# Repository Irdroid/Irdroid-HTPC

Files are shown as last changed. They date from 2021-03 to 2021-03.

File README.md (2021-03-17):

**Irdroid HTPC Infrared Remote Control Receiver for Kodi and alternatives**
-
**Introduction** 

The Irdroid-HTPC is a USB Infrared Remote Control receiver for HTPC media centers such as  KODI, Plex, Emby, OSMC, Jellyfin, Stremio etc. It enumerates on the host system as a standard HID input device (keyboard) and sends keystrokes to the host system based on the pressed TV remote control key. .(https://irdroid.eu/product/irdroid-htpc-infrared-remote-control-receiver-kodi-alternatives/)

**Product Photo:**
-

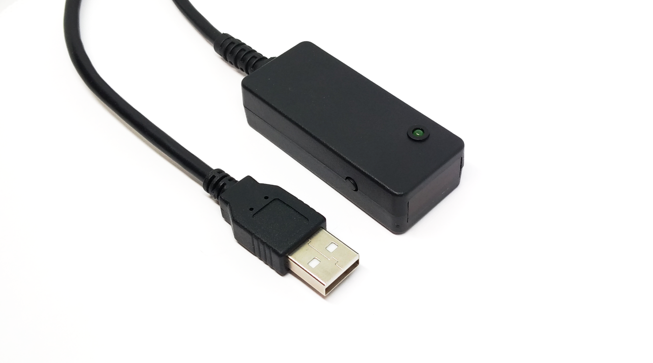
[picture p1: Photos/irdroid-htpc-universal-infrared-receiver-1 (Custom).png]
Irdroid-HTPC


**Features:**
-
- Usb Infrared remote control receiver for your HTPC that supports Kodi, Plex, Emby etc.
- Control your HTPC with your TV remote or any other remote
- No drivers needed, enumerates as a usb keyboard
- Infrared receiver with ultra wide reception angle with great sensitivity
- Kodi addon for activating shortcuts for Favourites and Weather via a single button.
- Velcro dots for fixing the unit in a position

**Supported Operating Systems**
-
- GNU Linux
- Mac OS X
- MS Windows
- Android

In addition to the above the module is open source hardware and software , so if you need to do any changes or fork your own version you are free to do so!
Its shipped with the micronucleus bootloader, compatible with the Arduino IDE and in a manner of minutes you can do whatever changes you need by simply plugging the usb cable of the device to your pc and changing the code as per your needs.
Irdroid-HTPC Remote Receiver has a great range and you don’t have to point your remote control directly toward the device it in order to control your media center.

**You have the following keystrokes available for remotely controlling your media center:**
- UP
- DOWN
- LEFT
- RIGHT
- OK/Enter
- Back
- Navigate to Favourites
- Navigate to Weather
- Play/Pause
 
With the above you get full control of your HTPC media center and if you need additional keystrokes / more control you can reprogram it by using the Arduino IDE.

**Product website and Documentation**
-
- [Irdroid-HTPC product Website](https://irdroid.eu/product/irdroid-htpc-infrared-remote-control-receiver-kodi-alternatives/)
- [Documentation, Schematics, Production files and Software for Brickz can be found in this repository.](https://github.com/Irdroid/Irdroid-HTPC)

**Purchase sample unit**
-
- [Irdroid-HTPC product Website](https://irdroid.eu/product/irdroid-htpc-infrared-remote-control-receiver-kodi-alternatives/)

**You want to help with the development?**
-
- Write us an email to info@irdroid.com

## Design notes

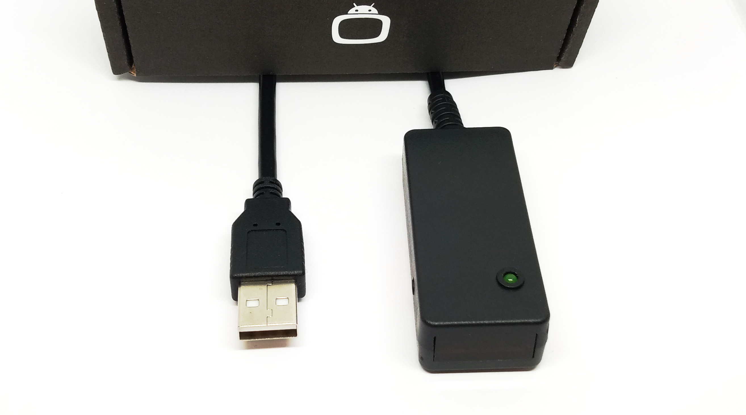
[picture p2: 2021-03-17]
Photos/irdroid-htpc-universal-infrared-receiver-2.png

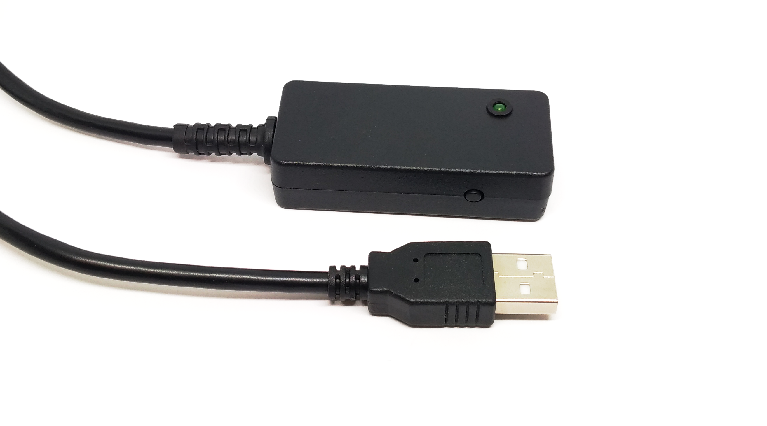
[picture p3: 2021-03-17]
Photos/irdroid-htpc-universal-infrared-receiver-3.png

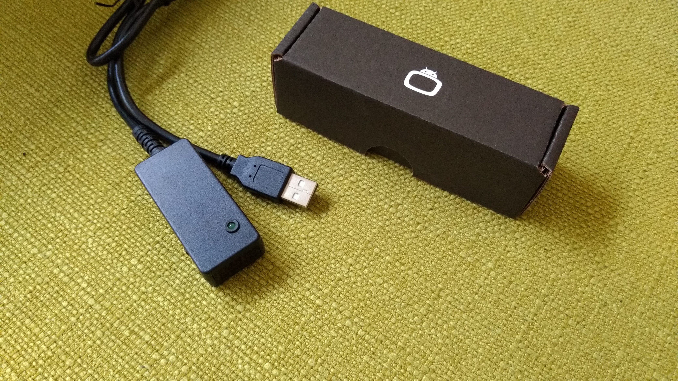
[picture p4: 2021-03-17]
Photos/irdroid-htpc-universal-infrared-receiver-blog2.jpg

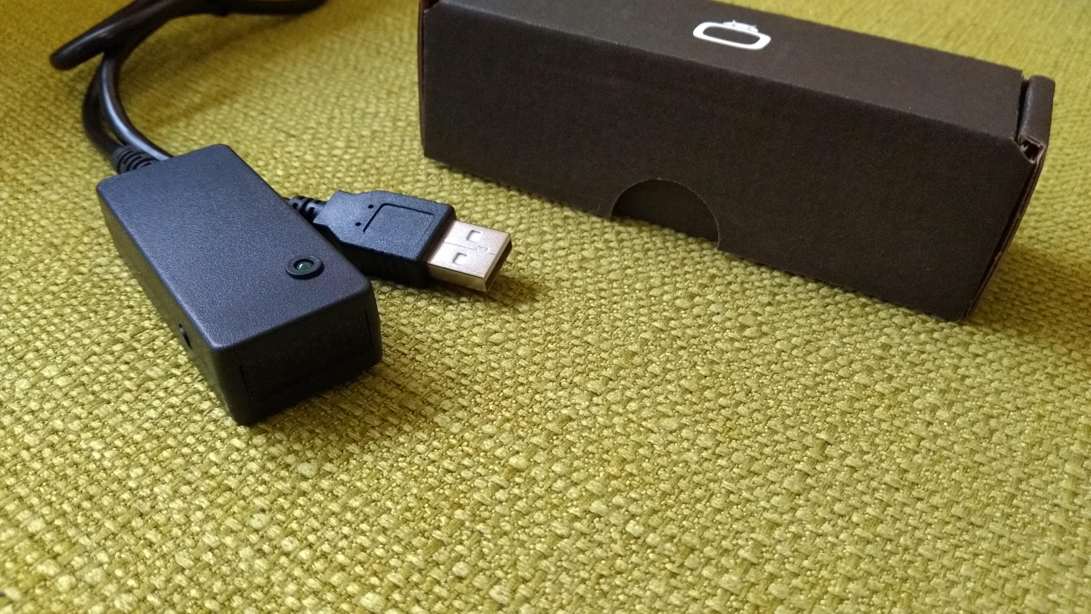
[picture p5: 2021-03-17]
Photos/irdroid-htpc-universal-infrared-receiver-blog1.jpg

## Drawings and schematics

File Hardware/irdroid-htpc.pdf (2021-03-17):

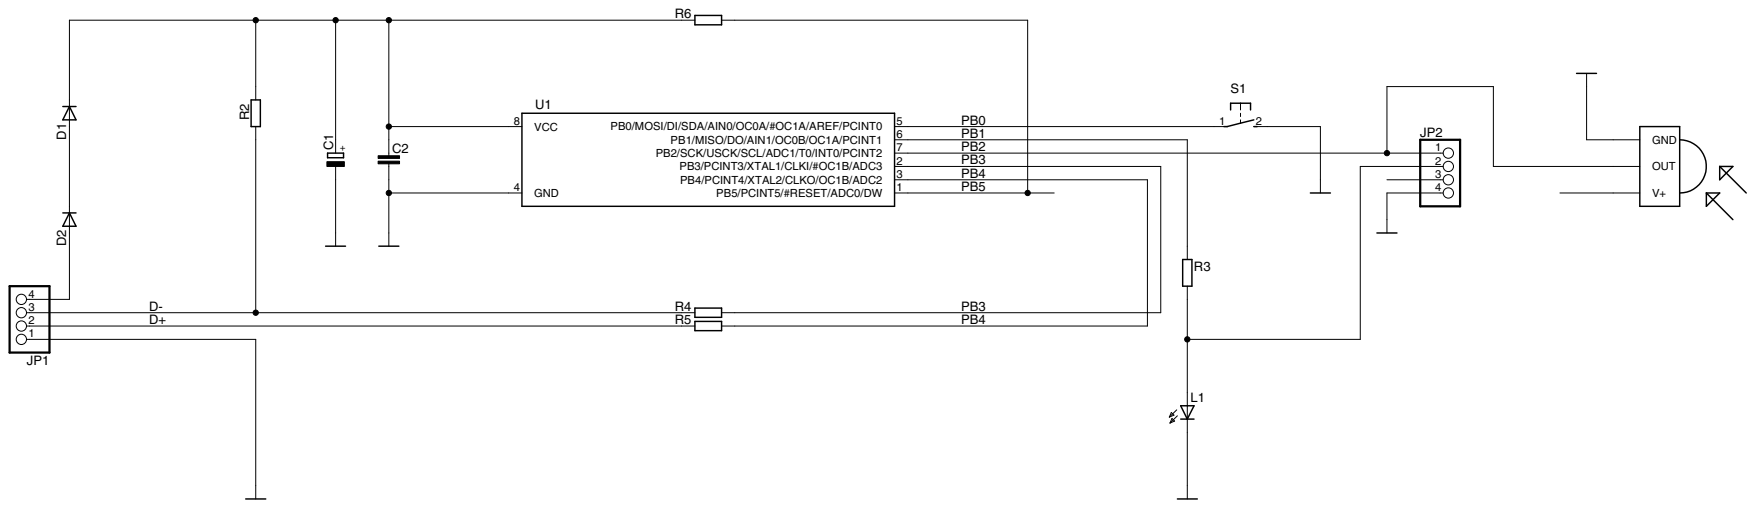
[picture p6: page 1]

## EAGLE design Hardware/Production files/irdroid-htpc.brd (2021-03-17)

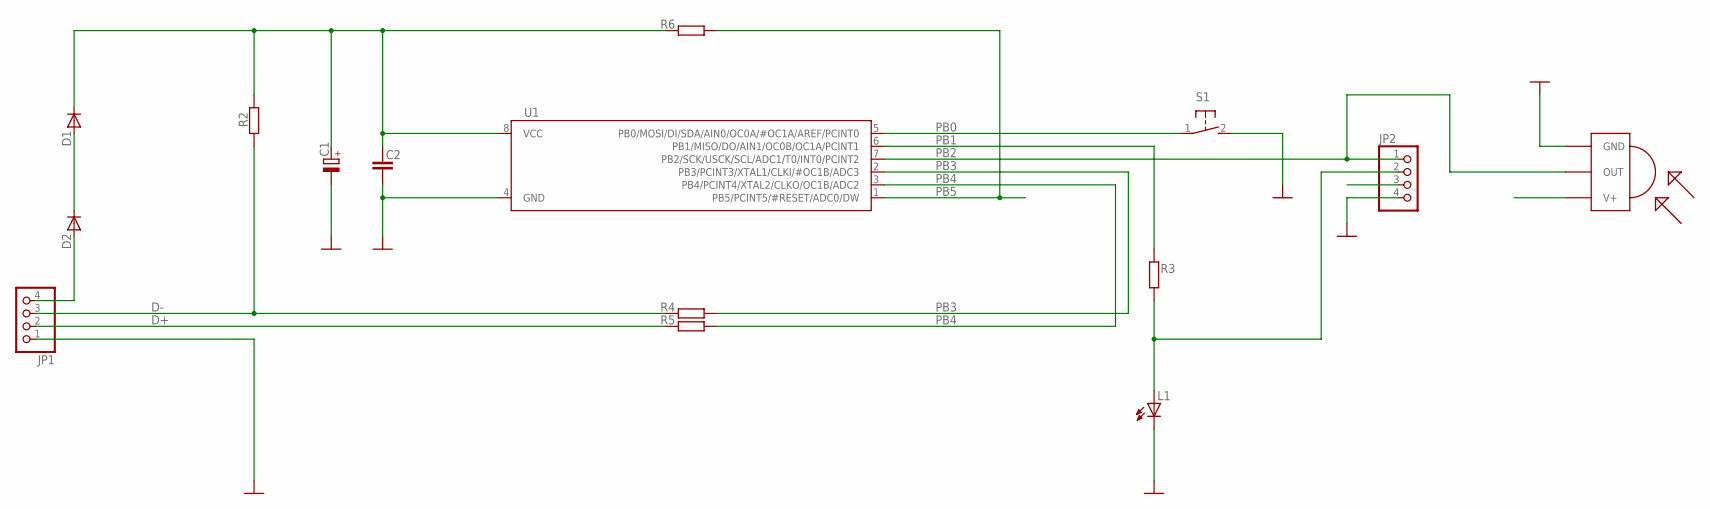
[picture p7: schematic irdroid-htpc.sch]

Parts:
C1: CPOL-EUE2-5; E2-5
C2: C-EU025-025X050; C025-025X050
D1, D2: DDO35; DO35-200MILS
JP1, JP2: PINHD-1X4; 1X04
L1: LED3.0MM; LED-3.0MM
R2, R3, R4, R5, R6: R-EU_0204/5; 0204/5
S1: 31-XX; B3F-31XX
U1: ATTINY85-20PU; DIP8
U$1: TSOP1838; TSOP18XX

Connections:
D+: JP1.2, R5.1
D-: JP1.3, R2.1, R4.1
GND: C1.-, C2.2, JP1.1, JP2.4, L1.K (C), S1.2 (S), U1.4 (GND), U$1.GND
unnamed: D1.A, D2.K
unnamed: JP2.2, L1.A, R3.1
PB0: S1.1, U1.5 (PB0/MOSI/DI/SDA/AIN0/OC0A/#OC1A/AREF/PC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)
PB1: R3.2, U1.6 (PB1/MISO/DO/AIN1/OC0B/OC1A/PCINT1)
PB2: JP2.1, U1.7 (PB2/SCK/USCK/SCL/ADC1/T0/INT0/PCINT2), U$1.OUT
PB3: R4.2, U1.2 (PB3/PCINT3/XTAL1/CLKI/#OC1B/ADC3)
PB4: R5.2, U1.3 (PB4/PCINT4/XTAL2/CLKO/OC1B/ADC2)
PB5: R6.2, U1.1 (PB5/PCINT5/#RESET/ADC0/DW)
VBUS: D2.A, JP1.4
VCC: C1.+, C2.1, D1.K, JP2.3, R2.2, R6.1, U1.8 (VCC), U$1.VCC (V+)

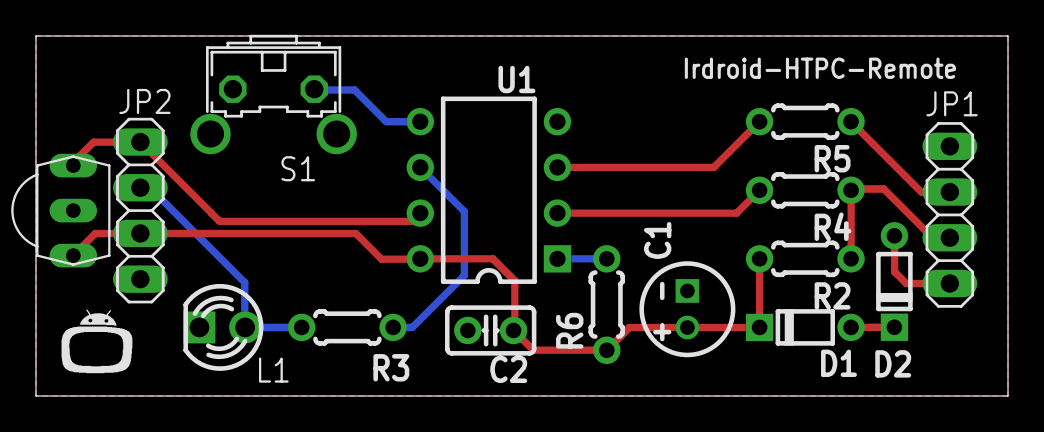
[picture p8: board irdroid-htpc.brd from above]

Board: 2 copper layers, 54.0 x 20.0 mm, 16 parts (0 on the bottom side), 13 nets.

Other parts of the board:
U$2: IRDROIDLOGO

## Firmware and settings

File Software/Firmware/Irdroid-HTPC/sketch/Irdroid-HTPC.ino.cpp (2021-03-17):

#include <Arduino.h>
#line 1 "C:\\Users\\bakalski\\Documents\\GitHub\\Irdroid-HTPC\\Software\\Firmware\\Irdroid-HTPC\\Irdroid-HTPC.ino"
#line 1 "C:\\Users\\bakalski\\Documents\\GitHub\\Irdroid-HTPC\\Software\\Firmware\\Irdroid-HTPC\\Irdroid-HTPC.ino"
// **** TSOP is connected to port PB2 **** //////
#define REPEAT_DELAY 150
#include <EEPROM.h>
//Set to 0 after finding your codes
bool DEBUG = false;

//Specify your remote codes here:

uint32_t REMOTE_UP = 0;
uint32_t REMOTE_DOWN = 0;
uint32_t REMOTE_LEFT = 0;
uint32_t REMOTE_RIGHT = 0;
uint32_t REMOTE_OK=0;
uint32_t REMOTE_RETURN =0;
uint32_t REMOTE_PLAY =0;
uint32_t REMOTE_NEXT =0;
uint32_t REMOTE_PREVIOUS =0;


unsigned int counter = 0;

// Variables will change:
int buttonPushCounter = 0;   // counter for the number of button presses
int buttonState = 0;         // current state of the button
int lastButtonState = 0;     // previous state of the button





volatile uint8_t m = 0, tcnt = 0, startflag = 0;
uint32_t irdata = 0, keydata = 0 ;
uint32_t key_tmp = 0;
bool pressed = false;
bool complete = false;
unsigned int count;
#include <avr/delay.h>
#include "TrinketHidCombo.h"

#line 40 "C:\\Users\\bakalski\\Documents\\GitHub\\Irdroid-HTPC\\Software\\Firmware\\Irdroid-HTPC\\Irdroid-HTPC.ino"
long EEPROMReadlong(int address);
#line 49 "C:\\Users\\bakalski\\Documents\\GitHub\\Irdroid-HTPC\\Software\\Firmware\\Irdroid-HTPC\\Irdroid-HTPC.ino"
void EEPROMWritelong(int address, uint32_t value);
#line 64 "C:\\Users\\bakalski\\Documents\\GitHub\\Irdroid-HTPC\\Software\\Firmware\\Irdroid-HTPC\\Irdroid-HTPC.ino"
void setup();
#line 96 "C:\\Users\\bakalski\\Documents\\GitHub\\Irdroid-HTPC\\Software\\Firmware\\Irdroid-HTPC\\Irdroid-HTPC.ino"
void loop();
#line 190 "C:\\Users\\bakalski\\Documents\\GitHub\\Irdroid-HTPC\\Software\\Firmware\\Irdroid-HTPC\\Irdroid-HTPC.ino"
void ms_delay(uint16_t x);
#line 198 "C:\\Users\\bakalski\\Documents\\GitHub\\Irdroid-HTPC\\Software\\Firmware\\Irdroid-HTPC\\Irdroid-HTPC.ino"
void Action(uint32_t keycode);
#line 40 "C:\\Users\\bakalski\\Documents\\GitHub\\Irdroid-HTPC\\Software\\Firmware\\Irdroid-HTPC\\Irdroid-HTPC.ino"
long EEPROMReadlong(int address) {
  long four = EEPROM.read(address);
  long three = EEPROM.read(address + 1);
  long two = EEPROM.read(address + 2);
  long one = EEPROM.read(address + 3);

  return ((four << 0) & 0xFF) + ((three << 8) & 0xFFFF) + ((two << 16) & 0xFFFFFF) + ((one << 24) & 0xFFFFFFFF);
}

void EEPROMWritelong(int address, uint32_t value) {
  byte four = (value & 0xFF);
  byte three = ((value >> 8) & 0xFF);
  byte two = ((value >> 16) & 0xFF);
  byte one = ((value >> 24) & 0xFF);
 
  EEPROM.write(address, four);
  EEPROM.write(address + 1, three);
  EEPROM.write(address + 2, two);
  EEPROM.write(address + 3, one);
}




void setup() {
  //delay(30000);
  pinMode(0, INPUT_PULLUP);
  count = 9;
   REMOTE_UP = EEPROMReadlong(70);
   REMOTE_DOWN = EEPROMReadlong(75);
   REMOTE_LEFT = EEPROMReadlong(80);
   REMOTE_RIGHT = EEPROMReadlong(85);
   REMOTE_OK = EEPROMReadlong(90);
   REMOTE_RETURN = EEPROMReadlong(95);
   REMOTE_PLAY = EEPROMReadlong(100);

   REMOTE_NEXT = EEPROMReadlong(110);
   REMOTE_PREVIOUS = EEPROMReadlong(115);
  DDRB |= (1 << DDB1); //P1 (LED) OUT not used in sketch
  PORTB |= 1 << PB2; // a PB2 lift will not hurt.
   PCMSK = (1<<PCINT3) | (1<<PCINT4);
  // Enable PCINT interrupts
  GIMSK = (1<<PCIE);
  GIMSK |= 1 << INT0; //interrupt int0 enable
   sei();
  MCUCR |= 1 << ISC00; //Any logical change on INT0 generates an interrupt request
  GTCCR |= 1 << PSR0; TCCR0A = 0;
  TCCR0B = (1 << CS02) | (1 << CS00); // divider /1024
  TIMSK = 1 << TOIE0; //interrupt Timer/Counter1 Overflow  enable
  TrinketHidCombo.begin(); // start the USB device engine and enumerate

 
  
   
}

void loop() {
  


   buttonState = digitalRead(0);
   
     // compare the buttonState to its previous state
  if (buttonState != lastButtonState) {
    // if the state has changed, increment the counter
    if (buttonState == LOW) {
      
  
    DEBUG = true;
      // if the current state is HIGH then the button went from off to on:
      buttonPushCounter++;

      
        count--;
   
    
  // TrinketHidCombo.println(count);
     
    } else {
      // if the current state is LOW then the button went from on to off:
    
      DEBUG = false;
     
     
    
       
        
    }
    // Delay a little bit to avoid bouncing
    delay(50);
  }
  // save the current state as the last state, for next time through the loop
  lastButtonState = buttonState;
      
  if (complete) { // if a code has been received
    
    key_tmp = 0;
   
    if (keydata != 0) //if a code is new
    {
      Action(keydata);
      pressed = true;
    }

       
    
   //  TrinketHidCombo.mouseMove(lastMouseX, lastMouseY, 0);

    complete = false;
    ms_delay(REPEAT_DELAY);// to balance repeating/input delay of the remote

  }
  else if (pressed)
  {
    digitalWrite(1, LOW);
   
      TrinketHidCombo.pressKey(0, 0);
    pressed = false;
  }
  else
  {
    _delay_ms(1);//restrain USB polling on empty cycles
    TrinketHidCombo.poll(); // check if USB needs anything done
  }

}

ISR (INT0_vect) {
  if (PINB & 1 << 2) { // If log1
    TCNT0 = 0;
  }
  else {
    tcnt = TCNT0; // If log0
    if (startflag) {
      if (30 > tcnt  && tcnt > 2) {
        if (tcnt > 15 && m < 32) {
          irdata |= (2147483648 >> m);
        }
        m++;
      }
    }
    else  startflag = 1;
  }
}
ISR (TIMER0_OVF_vect) {
  if (m)
    complete = true; m = 0; startflag = 0; keydata = irdata; irdata = 0; // if the index is not 0, then create an end flag
   
}

void ms_delay(uint16_t x) // USB polling delay function
{
  for (uint16_t m = 0; m < (x / 10); m++) {
    _delay_ms(10);
    TrinketHidCombo.poll();
  }
}

void Action(uint32_t keycode)
{
 
  if(keycode == REMOTE_UP && !DEBUG ){
    TrinketHidCombo.pressKey(0, KEYCODE_ARROW_UP);
    digitalWrite(1, HIGH);
    return;
  }
  if(keycode == REMOTE_DOWN && !DEBUG){
    TrinketHidCombo.pressKey(0, KEYCODE_ARROW_DOWN);
     digitalWrite(1, HIGH);
    return;
  }
  if(keycode == REMOTE_LEFT && !DEBUG){
    TrinketHidCombo.pressKey(0, KEYCODE_ARROW_LEFT);
     digitalWrite(1, HIGH);
    return;
  }
  if(keycode == REMOTE_RIGHT && !DEBUG){
    TrinketHidCombo.pressKey(0, KEYCODE_ARROW_RIGHT);
     digitalWrite(1, HIGH);
    return;
  }
  if(keycode == REMOTE_OK && !DEBUG){
    TrinketHidCombo.pressKey(0, KEYCODE_ENTER);
     digitalWrite(1, HIGH);
    return;
  }
  if(keycode == REMOTE_RETURN && !DEBUG){
    TrinketHidCombo.pressKey(0, KEYCODE_BACKSPACE);
     digitalWrite(1, HIGH);
    return;
  }
  if(keycode == REMOTE_PLAY && !DEBUG){
    TrinketHidCombo.pressMultimediaKey(MMKEY_PLAYPAUSE);
     digitalWrite(1, HIGH);
    return;
  }
   if(keycode == REMOTE_NEXT && !DEBUG){
   TrinketHidCombo.pressMultimediaKey(MMKEY_SCAN_NEXT_TRACK);
     digitalWrite(1, HIGH);
    return;
  }
   if(keycode == REMOTE_PREVIOUS && !DEBUG){
    TrinketHidCombo.pressMultimediaKey(MMKEY_SCAN_PREV_TRACK);
     digitalWrite(1, HIGH);
    return;
  }
  switch (keycode)
  {



 

    default:
      if(DEBUG){
       // TrinketHidCombo.println(keydata, HEX);
      key_tmp = 0;
      key_tmp = keycode;
 
       if(count==8){
          EEPROMWritelong(70, key_tmp);
          delay(100);
           REMOTE_UP = key_tmp;
           
       }
       if(count==7){
          EEPROMWritelong(75, key_tmp);
          delay(100);
          REMOTE_DOWN = key_tmp;
               
       }
        if(count==6){
          EEPROMWritelong(80, key_tmp);
          delay(100);
           REMOTE_LEFT = key_tmp;
       }
       if(count==5){
          EEPROMWritelong(85, key_tmp);
          delay(100);
          REMOTE_RIGHT = key_tmp;
               
       }
        if(count==4){
          EEPROMWritelong(90, key_tmp);
          delay(100);
           REMOTE_OK = key_tmp;
       }
       if(count==3){
          EEPROMWritelong(95, key_tmp);
          delay(100);
          REMOTE_RETURN = key_tmp;
        //  count = 6;     
       }
       if(count==2){
          EEPROMWritelong(100, key_tmp);
          delay(200);
          REMOTE_PLAY = key_tmp;
        
       }
       
        if(count==1){
          EEPROMWritelong(110, key_tmp);
          delay(200);
          REMOTE_NEXT = key_tmp;
        
       }
        if(count==0){
          EEPROMWritelong(115, key_tmp);
          delay(200);
          REMOTE_PREVIOUS = key_tmp;
          count = 9;
        
       }
    
        
      
       
      }else{
        return;
      }
      
  }
  digitalWrite(1, HIGH);
}
